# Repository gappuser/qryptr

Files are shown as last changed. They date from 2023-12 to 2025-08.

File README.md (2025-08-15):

# qryptr - airgapped ecc text messenger

Are you a smartphone user worried about [spyware](https://en.wikipedia.org/wiki/Spyware), [advanced actors](https://en.wikipedia.org/wiki/Advanced_persistent_threat), [backdoors](https://en.wikipedia.org/wiki/Backdoor_(computing)), [zero-days](https://en.wikipedia.org/wiki/Zero-day_vulnerability) or [side-channel attacks](https://en.wikipedia.org/wiki/Side-channel_attack)? These routinely bypass end-to-end encryption through keyloggers, screen capture and compromised keys. Smartphones are part of complex ecosystems with dozens of hardware and software components and remain vulnerable despite vendor and political efforts.

We introduce a simple, offline, airgapped device to counter such threats. 

Plain text messages are ECC encrypted and displayed as QR codes. These QR codes can be photographed and shared using your smartphone. This method offers additional endpoint security as plaintext and cryptographic keys are physically seperated from your smartphone.

This repository contains all hardware and software to create such a device, which allows text messages of up to 299 characters.

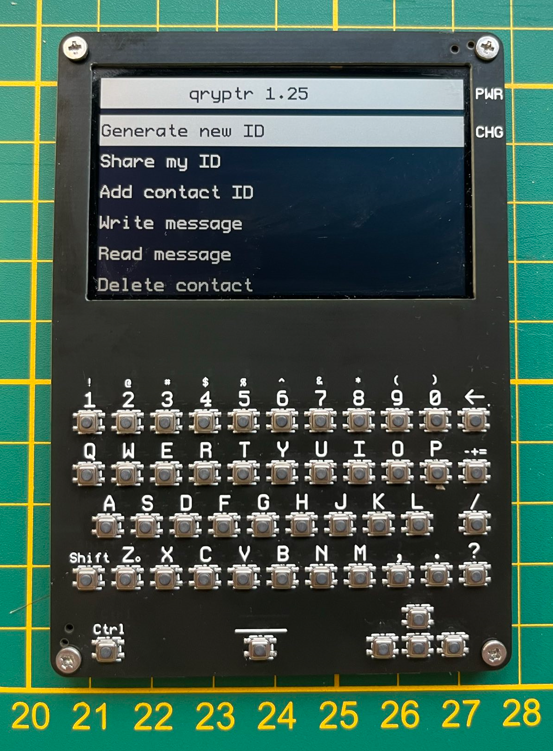
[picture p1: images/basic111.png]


# How it works
The device has cryptographic software, a keyboard, camera, screen and is based on the RP2040 microcontroller.

Each user has a device. Upon receiving it, the user can generate his/her ECC keypair. The user's ECC keypair uniquely identifies him/her, that is why it is referred to as the user ID.

The public key of the user ID can be displayed as a QR code. Another user can add that user ID scanning it. This is preferably done in-person, not remotely, to prevent man-in-the-middle attacks. 

After two users have added each others' ID's, they can write text messages which are ECC encrypted, base64 encoded and displayed as QR codes.

Using their smartphones, users can photograph/share these QR-codes with their preferred messaging app, such as Signal, Whatsapp, Telegram, Viber, or even email or print the QR codes.

The recipient can scan the QR code with his/her device, which will read, decode, decrypt and display the text message. The recommended read distance is 10 cm between smartphone screen and camera. The letter "Z" is marked on the frontpanel to help a user center the qr code in front of the camera.

### Share and add IDs

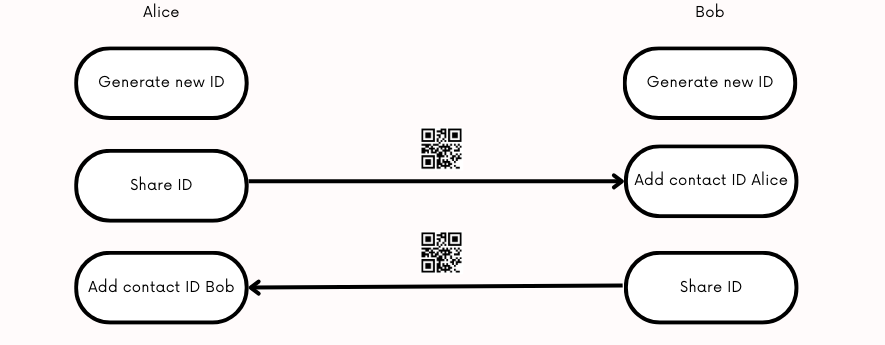
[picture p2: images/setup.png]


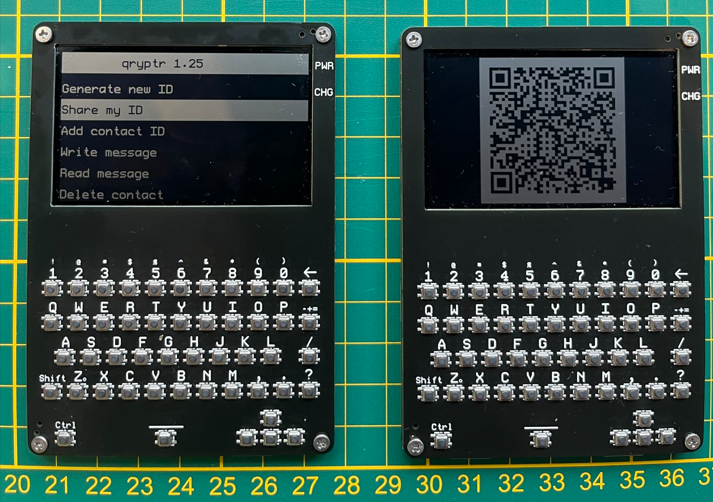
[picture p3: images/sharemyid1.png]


### Write and read messages

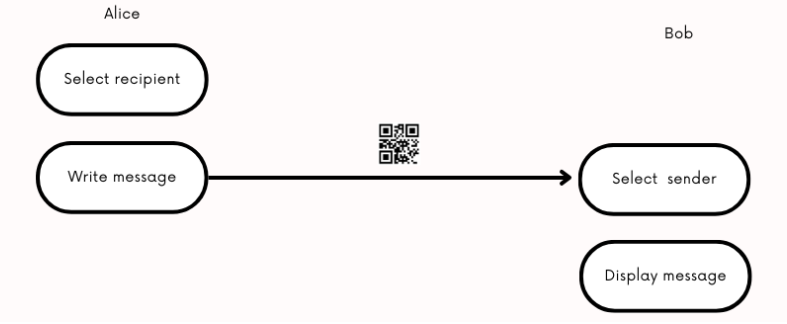
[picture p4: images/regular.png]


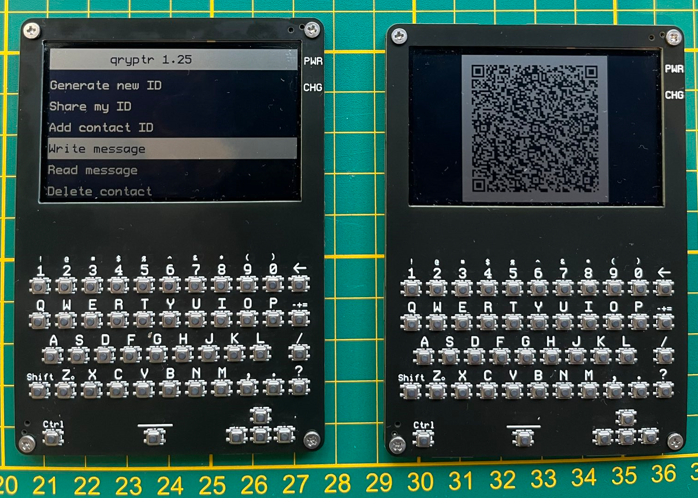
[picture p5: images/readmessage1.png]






# Use cases
-Sharing sensitive information between journalists, lawyers, political actors or civil servants.

-Sharing passwords between system administrators.

-Sharing passwords for crypto wallets.

-Sharing key material or passwords for HSM procedures.

-Thwart spyware or advanced threats.

# Implementation
## hardware
### Printed Circuit Boards (PCBs)
The device consists of 2 printed circuit boards (PCBs): a mainplate and frontplate with keys. We chose a microcontroller platform to minimize platform complexity and dependencies: the RP2040. Design files are available in the /hardware folder. With the Gerber, BOM and pick-and-place files, you can order directly from jlcpcb.com or other PCB manufacturers. 

Alternatively, you can view or clone these at the following urls to make adjustments.

https://oshwlab.com/thomas255/mainplate-public (click "clone")  

https://oshwlab.com/thomas255/frontplate-public (click "clone")

### Camera

QR codes are read using a hardware camera, the GM803, available on aliexpress. Get the GM803-S version with short focal range. This camera will read the QR code towards the serial interface of the RP2040.

### Display

We are using the Sharp LS027B7DH01 display, available on aliexpress. It is flat, requires few components, has a high resolution and low power requirements. Other u8g2 supported displays could be used as well with some adjustments.

### Other parts

Some parts needs to be ordered seperately from [lscs.com](https://www.lcsc.com/):

-LCSC#: C2911889 Clamshell 18P Bottom Contact Surface Mount FFC connector. We order this part seperately to solder it manually so that we can use one sided PCB assembly at JLCPCB to save costs. Alternatively, two sided assembly for the frontplate can be used at JLCPCB, in which case this part does not need to be ordered seperately.

-LCSC#: C2857713 18P Opposite Side 5cm P=0.5mm flat flexible cable to connect the frontplate (keyboard) with the mainplate

-LCSC#: C5151979 12P Opposite Side 5cm P=0.5mm flat flexible cable to connect the GM-803 camera to the mainplate

-M2 nuts and M2 bolts of 3mm length.

-A plastic spacer between the mainplate and frontplate, for mechanical stability and assembly, which can be 3d printed with the provided ./hardware/spacer.stl file.

-A 302040 lipo battery: https://www.aliexpress.com/item/33009055815.html

## software
We use the Arduino IDE.

Go to the board manager and install Arduino mbed OS RP2040 Boards (3.5.4). This should set target_platform=mbed_rp2040 in preferences.txt for the arduino IDE.

We use the Arduino mbed_rp2040 target platform, because we want to use the Sharp LS027B7DH01 display, and the earle philhower core does not allow changing the HW SPI pin assignment. We want to use different pins for driving the SPI display in the u8g2 display constructor, because the original pin assignment is very slow.

Using the library manager in the Arduino IDE, install the following libraries:

-QRCode by Richard Moore (https://github.com/ricmoo/qrcode/)

-U8G2 by Oliver Kraus (https://github.com/olikraus/u8g2)

-Crypto by Rhys Weatherley and Brandon Wiley (https://github.com/OperatorFoundation/Crypto)

To upload the software, connect with PC through USB, turn on device, upload ./software/qryptr.ino through the arduino IDE. If that does not work, there is a reset button. Turn off the device, hold the reset button, connect with PC, release the reset button. Then upload the arduino sketch through the arduino IDE.

Once uploaded, navigate the menu with the arrow buttons (left, right, up, down). There is no enter key. To select an option or continue, use the right arrow. You can always go back with left arrow or interrupt reading by pressing any key.

# Todos
## hardware
-Add resistor divider to measure the battery voltage

-Expose SWD pins on PCB to enable loading the software through SWD pins. This will allow us to disconnect the datalines from the USB port and prevent an attack vector.

-Improve keyboard

-Use rp2350 TRNG and possibly secure boot.

-RF and audio shielding to prevent side channel attacks.

-Use the HM01B0 camera instead.

## software
-Replace Arduino Crypto library with Monocypher (https://github.com/LoupVaillant/Monocypher). Monocypher is more widely used and more regularly updated.

-Create a software procedure to turn the camera on/off to save power.

-Implement soft poweroff after timeout.

-Implement symmetric encryption on the long-term private key of the user. This will require a password prompt for decrypting messages. Possibly use 2 passwords, a long one for starting up, and a shorter one for decrypting/encrypting.

-Enable multiple personal ID's (cryptographic keys)

-Add start and end tags for messages and keys, so that it is clear whether a valid messages/key was received. This will prevent bad reads from crashing the device as well.

-Use camera without character encoding (raw bytes).

-Write special characters (diacritics) with ctrl button.

-On screen arrows to make navigation more intuitive.

-Support reset-after-x-messages, to reset the device after decrypting or encrypting a certain amount of messages.

-Support multiple languages.

-Support deadman's switch, that is, reset the device upon startup if a wrong or particular password is used, or after a particular time period (though this is hard without a real time clock).

-Research backup-to-screen, that is, backup some contacts by displaying them on the screen and letting users decide how to back them up (writing them down or making a photo).

-Reshare keys to trusted contacts, possibly by signing them as well.

-Possible enable local, offline password manager.

# FAQ
## hardware
Q: Could we run the whole device on 3.3V? 

A: The Sharp LS027B7DH01 display requires 5V according to the specifications, although it seems to work on 3.3V as well. Possibly, the charge boost circuit could be left out if the display is used at 3.3V.

Q: Could we create a single PCB instead of a backplate and frontplate?

A: Yes, it could be done, although a singular PCB would need double-sided PCB assembly which is more expensive for small quantities @ JLCPCB. It likely would require a 4 layer PCB instead of 2 layer PCBs. Also, a seperate backplate would need to be introduced.

Q: How about using an epaper display instead of the Sharp display?

A: It has been considered, but the Sharp display has a higher refresh rate and is very flat and easy to integrate with just a couple of capacitors. The Sharp display is easy to use with the U8G2 library. There are other advantages to using epaper displays such as low glare which would make it easier to photograph the screen, so this could still be a good option.

## software
Q: How is encryption done?

A: Using the arduino Crypto library, with 32 byte ECC curve25519 keys, using ChaChaPoly cipher. Documented in the code, according to the procedure described here:

https://crypto.stackexchange.com/questions/101420/eccdh-direct-or-with-temporary-ecc-keypairs

# Assembly
Place the battery and solder the wires as shown below to the pads.

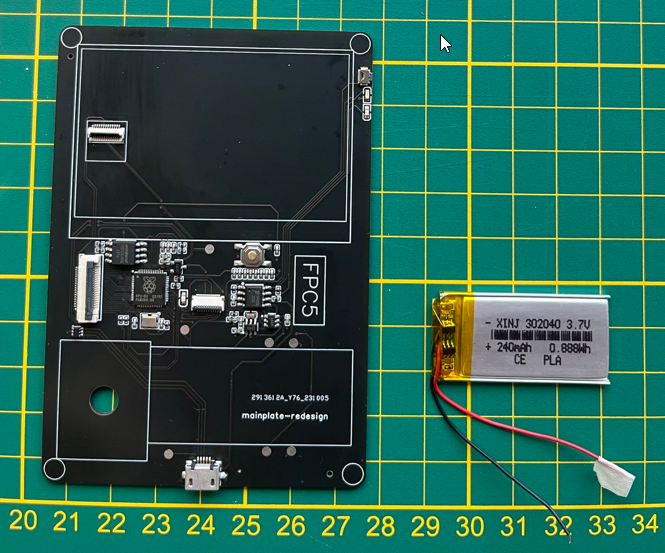
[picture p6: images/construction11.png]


Place the 3d printed spacer as shown below, insert the m2 nuts with some glue.

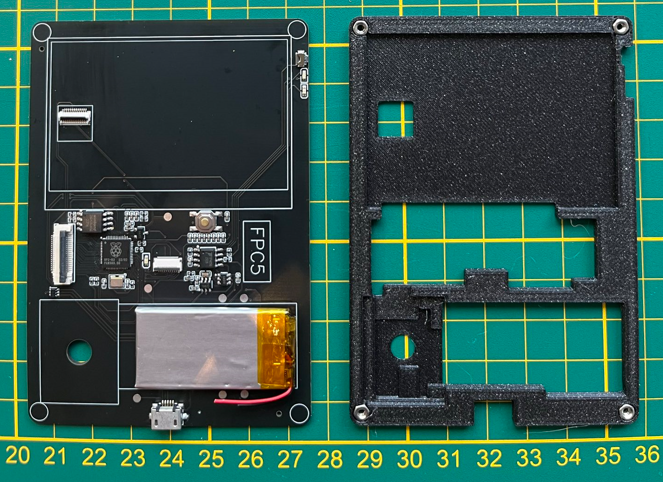
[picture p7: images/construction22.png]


Connect the 18 pin keyboard connector as shown below, place the GM-803 camera module and connect with the 12 pin ffc connector cable.

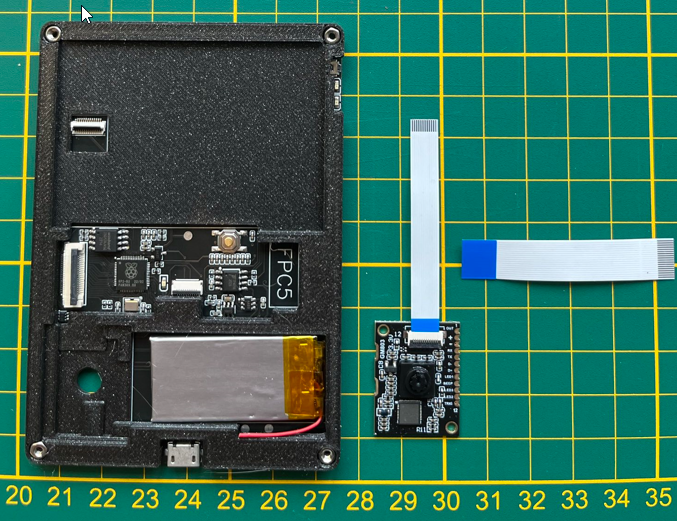
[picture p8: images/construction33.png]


Place the screen as shown below.

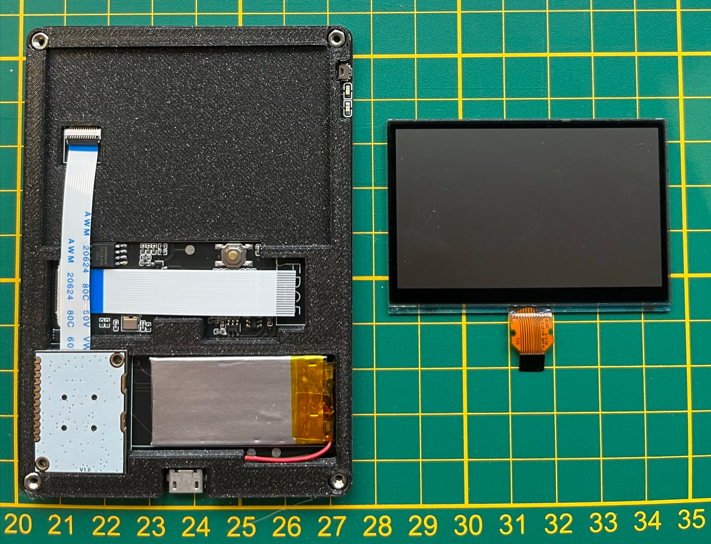
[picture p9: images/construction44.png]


Solder the frontplate 18 pin connector (or order an assembled frontplate from JLCPCB), and connect it. Soldering this 0.5mm pitch connector can be a bit tricky.

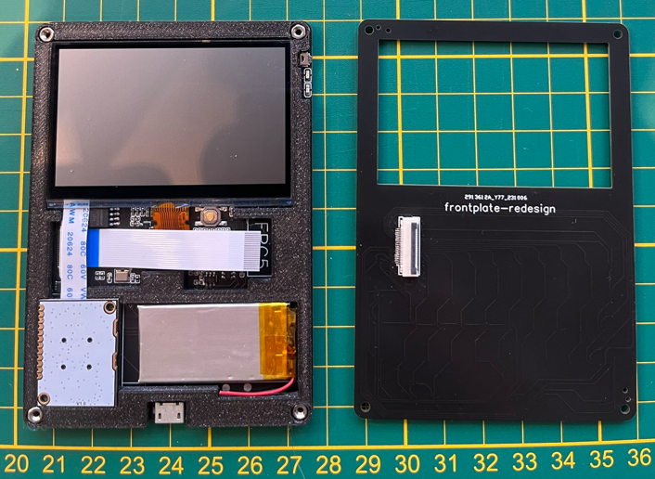
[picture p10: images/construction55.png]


Use the m2 3mm bolts to screw the frontplate down.

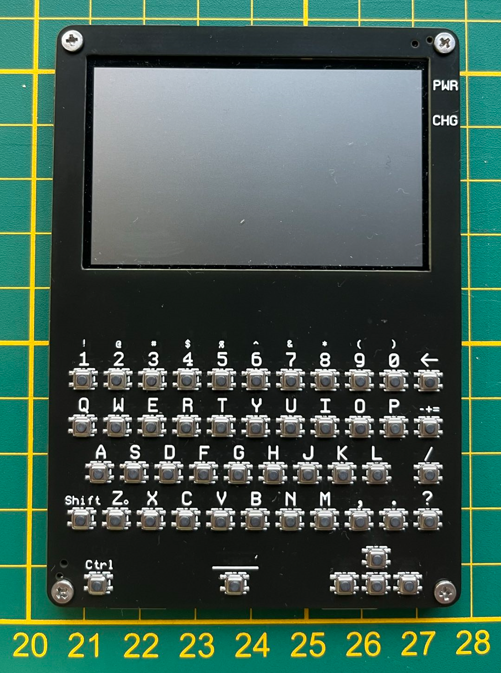
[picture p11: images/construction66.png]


## Setup GM803 camera

After charging, a green led will light up. Turn on the device (PWR top right push button). You have to enable serial output of the GM803 camera. To do so, scan the following QR codes.

### Reset (GM803 factory default)


### Enable serial output


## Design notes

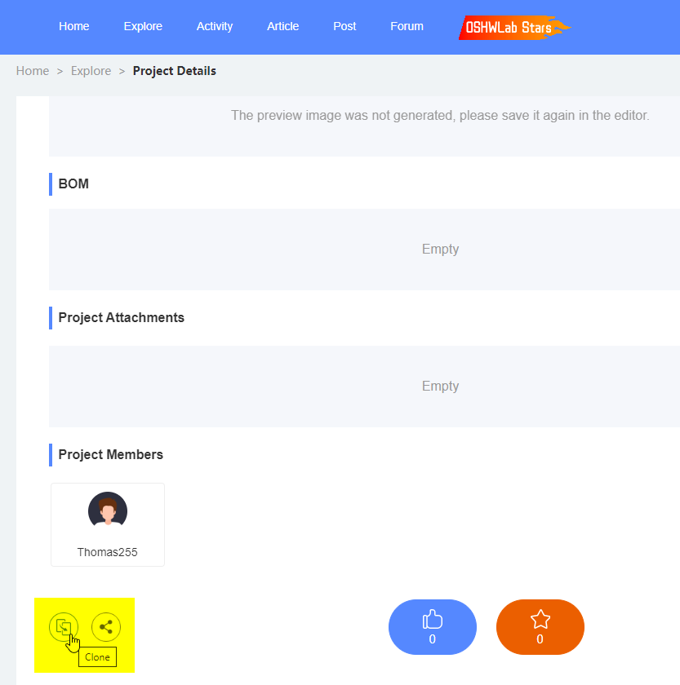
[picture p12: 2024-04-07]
images/clone.png

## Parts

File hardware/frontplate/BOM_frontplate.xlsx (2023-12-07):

No. | Quantity | Comment | Designator | Footprint | Value | Manufacturer Part | Manufacturer | Supplier Part | Supplier | Primary Category | Secondary Category
1 | 49 | TSA007B1518A | 0,1,2,3,4,5,6,7,8,9,+-1,//1,A1,B1,BACK1,C1,COMMA1,CTRL1,D1,DOT1,DOWN1,E1,F1,G1,H1,I1,J1,K1,L1,LEFT1,M1,N1,O1,P1,Q1,QM1,R1,RIGHT1,S1,SHIFT1,SPACE1,T1,U1,UP1,V1,W1,X1,Y1,Z1 | SW-SMD_4P-L3.4-W3.4-P2.00-LS4.0_YTSA007AXXXX |  | TSA007B1518A | BZCN(博众电气) | C2888918 | LCSC | Key/Switch | Tactile Switches
2 | 1 | 0.5K-DX-18PWBG | FPC2 | FPC-SMD_18P-P0.50_HDGC_0.5K-DX-18PWBG |  | 0.5K-DX-18PWBG | HDGC(华德共创) | C2911889 | LCSC | Connectors | FFC/FPC Connectors

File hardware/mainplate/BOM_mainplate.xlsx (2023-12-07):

No. | Quantity | Comment | Designator | Footprint | Value | Manufacturer Part | Manufacturer | Supplier Part | Supplier | Primary Category | Secondary Category
1 | 7 | 2MM ROUND PAD | 3VLDOOUT?,3.3VMINBAT1,3.3VMINBAT?,3.3VPLUSBAT1,3.3VPLUSBAT?,5VCHPOUT?,5VUSBOUT? | PAD 2MM*2MM
2 | 4 | 10kΩ | ADC_R1,MEMR1,TPR1,TPR2 | R0402 |  | 0402WGF1002TCE | UniOhm | C25744 | LCSC
3 | 11 | 100nF | CAMCAP1,CAPBANK1,CAPBANK2,CAPBANK3,CAPBANK4,CAPBANK5,CAPBANK6,CAPBANK7,CAPBANK8,CAPBANK9,MEMC1 | C0402_NEW |  | CL05B104KO5NNNC | SAMSUNG | C1525 | LCSC
4 | 5 | 10uF | CAMCAP2,CHPC1,CHPC2,TPC1,TPC2 | C0402 | 10uF | CL05A106MQ5NUNC | SAMSUNG(三星) | C15525 | LCSC | Capacitors | Multilayer Ceramic Capacitors MLCC - SMD/SMT
5 | 1 | 2.2uF | CHPC3 | C0603 |  | CL10A225KO8NNNC | SAMSUNG(三星) | C23630 | LCSC
6 | 1 | SD6210A-5V-CHARGEPUMP | CHPU1 | SOT-23-6_L2.9-W1.6-P0.95-LS2.8-BL |  | SD6210A | SHOUDING(首鼎半导体) | C250809 | LCSC
7 | 1 | THD0510-12CL-GF | FPC1 | FPC-SMD_12P-P0.50_THD0510-12CL-GF |  | THD0510-12CL-GF | THD(台华达) | C283122 | LCSC
8 | 1 | THD0509-10CL-GF | FPC2 | FPC-SMD_10P-P0.50_THD0509-10CL-GF |  | THD0509-10CL-GF | THD(台华达) | C283136 | LCSC | Connectors | FFC/FPC Connectors
9 | 1 | 0.5K-DX-18PWBG | FPC6 | FPC-SMD_18P-P0.50_HDGC_0.5K-DX-18PWBG |  | 0.5K-DX-18PWBG | HDGC(华德共创) | C2911889 | LCSC | Connectors | FFC/FPC Connectors
10 | 1 | XC6206P332MR | LDOU1 | SOT-23-3_L2.9-W1.6-P1.90-LS2.8-BR |  | XC6206P332MR | TOREX(特瑞仕) | C5446 | LCSC
11 | 1 | MAX16054AZT+T | MAX1 | TSOT-23-6_L2.9-W1.6-P0.95-LS2.8-TL |  | MAX16054AZT+T | MAXIM(美信) | C79401 | LCSC
12 | 2 | 1kΩ | MEMR2,XOSCR1 | R0402 |  | 0402WGF1001TCE | UniOhm | C11702 | LCSC
13 | 1 | TS-1187A-B-A-B | MEMSW1 | SW-SMD_4P-L5.1-W5.1-P3.70-LS6.5-TL-2 |  | TS-1187A-B-A-B | XKBConnectivity(中国星坤) | C318884 | LCSC
14 | 1 | W25Q128JVSIQTR | MEMU1 | SOIC-8_L5.3-W5.3-P1.27-LS8.0-BL |  | W25Q128JVSIQTR | WINBOND | C97521 | LCSC
15 | 1 | 19-217/BHC-ZL1M2RY/3T | PILED1 | LED0603-R-RD_BLUE |  | 19-217/BHC-ZL1M2RY/3T | EVERLIGHT | C72041 | LCSC
16 | 3 | 2kΩ | R3,TPRLED1,TPRLED2 | R0402 | 2kΩ | 0402WGF2001TCE | UNI-ROYAL(厚声) | C4109 | LCSC | Resistors | Chip Resistor - Surface Mount
17 | 2 | 10kΩ | R11,R12 | R0402 | 10kΩ | 0402WGF1002TCE | UNI-ROYAL(厚声) | C25744 | LCSC | Resistors | Chip Resistor - Surface Mount
18 | 3 | 1uF | SHARPC1,VREGC1,VREGC2 | C0402 |  | CL05A105KA5NQNC | SAMSUNG(三星) | C52923 | LCSC
19 | 1 | SMF05CT1G | STATIC1D? | SOT-363_L2.0-W1.3-P0.65-LS2.1-TL |  | SMF05CT1G | ON | C15879 | LCSC
20 | 1 | B3U-3000P | SW1 | KEY-SMD_B3U-3000P |  | B3U-3000P | OMRON(欧姆龙) | C963349 | LCSC | Key/Switch | Tactile Switches
21 | 1 | 19-217/GHC-YR1S2/3T | TPLEDG1 | LED-0603 |  | 19-217/GHC-YR1S2/3T | EVERLIGHT | C72043 | LCSC
22 | 1 | 19-213/Y2C-CQ2R2L/3T(CY) | TPLEDY1W? | LED0603-R-RD |  | 19-213/Y2C-CQ2R2L/3T(CY) | EVERLIGHT(亿光) | C72038 | LCSC
23 | 1 | TP4056 | TPU1 | SOP-8_EP_150MIL |  | TP4056 | TOPPOWER | C16581 | LCSC
24 | 1 | RP2040 | U1 | LQFN-56_L7.0-W7.0-P0.4-EP |  | RP2040 | RaspberryPi(树莓派) | C2040 | LCSC
25 | 1 | U-F-M5SS-W-1 | USB1 | MICRO-USB-SMD_U-F-M5SS-W-1 |  | U-F-M5SS-W-1 | 韩国韩荣 | C145783 | LCSC
26 | 2 | 22Ω | USBR1,USBR2 | R0402 |  | 0402WGF220JTCE | UniOhm | C25092 | LCSC
27 | 2 | 33pF | XOSCC1,XOSCC2 | C0402 |  | 0402CG330J500NT | FH | C1562 | LCSC
28 | 1 | 12MHz | XOSCX1 | OSC-SMD_4P-L3.2-W2.5-BL |  | X322512MSB4SI | YXC | C9002 | LCSC

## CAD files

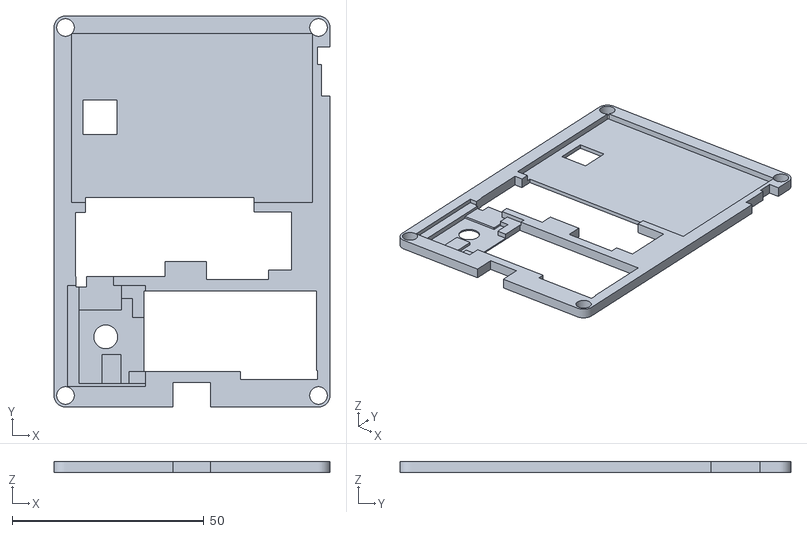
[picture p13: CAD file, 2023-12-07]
hardware/spacer.stl
72.0 x 102.0 x 3.00

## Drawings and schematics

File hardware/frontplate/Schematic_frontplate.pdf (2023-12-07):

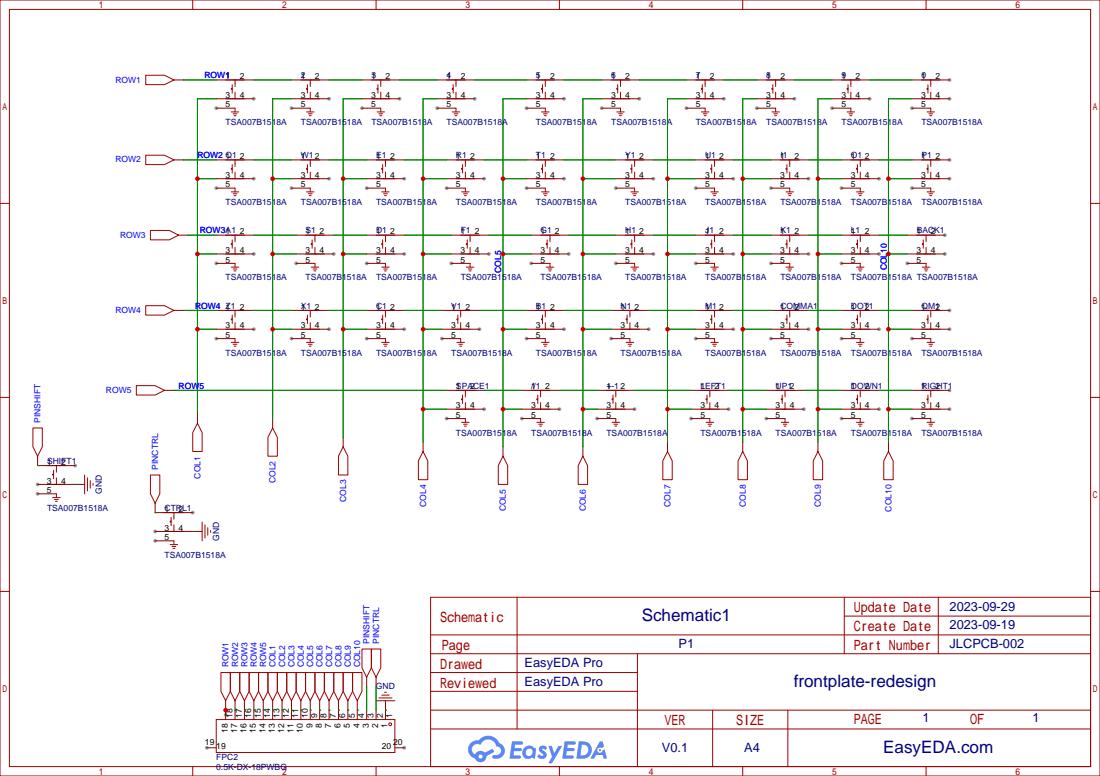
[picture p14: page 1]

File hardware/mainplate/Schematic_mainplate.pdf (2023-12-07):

# 0.5K-DX-18PWBG PICO_GP⁶_ROW⁵

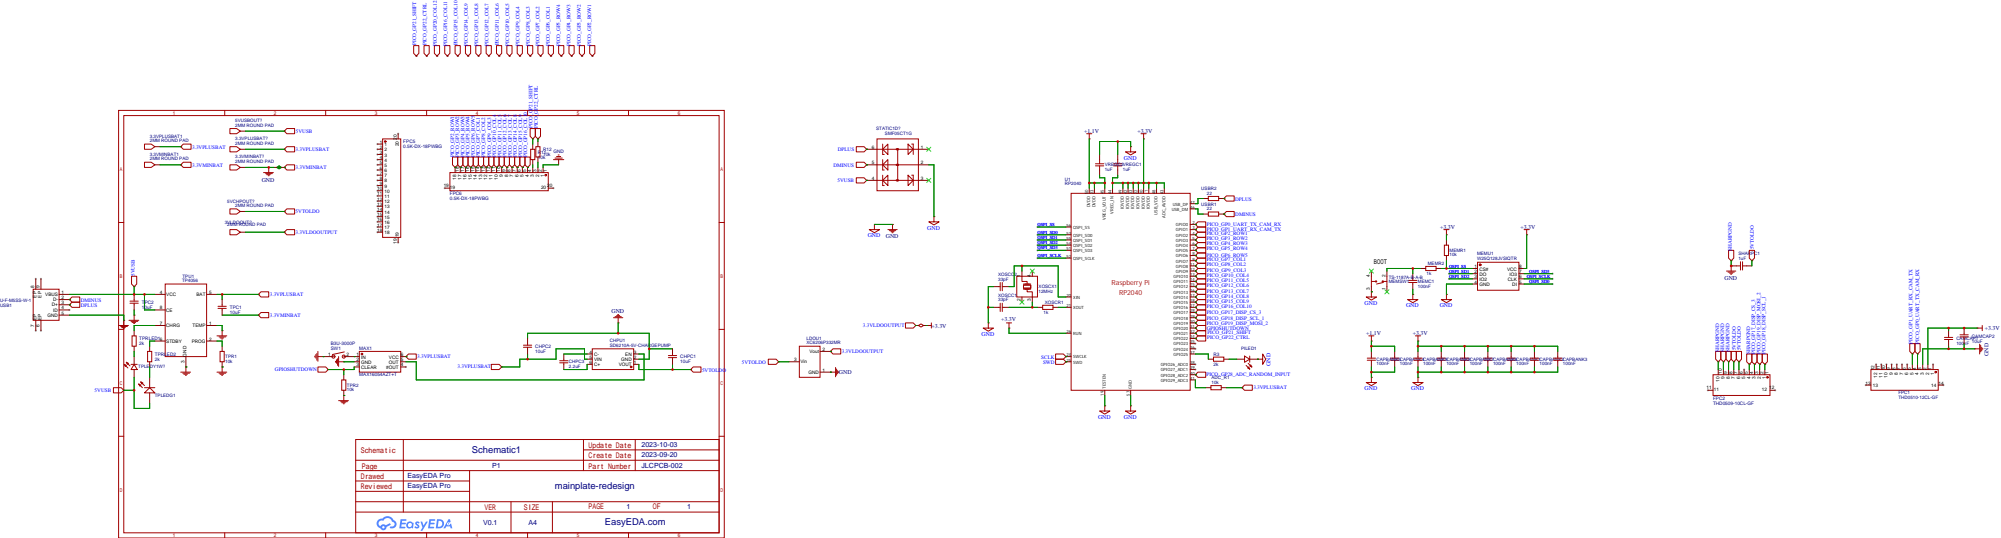
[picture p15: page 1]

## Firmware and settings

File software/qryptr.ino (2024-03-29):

//Copyright (C) 2024 Thomas Schellekens

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

//TODOS
//better prompts
//on screen arrows to indicate back/forth
//voltage readings of battery
//write special characters with control button
//multiple IDs
//use camera without character encoding. Currently, the GM-803 will always apply character encoding (UTF-8) to any byte. This means we need to apply base64 encoding before encoding into a QR code.
//Section 7.8 of the GM-803 manual seems to suggest there is a way to turn off character encoding, but this is not clear yet. We'd prefer to send raw bytes instead of base64-encoded raw bytes because it would allow for longer messages
//add option for symmetric encryption of private key (password prompt to make sure the private key is not kept in plain form on the memory chip)
//add <start> and <end> tags for messages and keys, so that upon decryption, it is clear whether a valid message was received or whether a error should be displayed


//Pin assignment
//Keyboard
//PICO_GP2_ROW1                                   
//PICO_GP3_ROW2  
//PICO_GP4_ROW3  
//PICO_GP5_ROW4  
//PICO_GP6_ROW5
//PICO_GP7_COL1
//PICO_GP8_COL2
//PICO_GP9_COL3
//PICO_GP10_COL4
//PICO_GP11_COL5
//PICO_GP12_COL6
//PICO_GP13_COL7
//PICO_GP14_COL8
//PICO_GP15_COL9
//PICO_GP16_COL10
//Display
//PICO_GP17_DISP_CS_3 
//PICO_GP18_DISP_SCL_1 
//PICO_GP19_DISP_MOSI_2 
//GP_20 GPIOSHUTDOWN        (todo for soft shutdown/timeout shutdown)
//PICO_GP21_SHIFT
//PICO_GP22_CTRL
//GP_23 unused
//GP_24 unused
//GP25 PI_LED for testing purposes
//GP28 ADC2 random input for ring oscillator (rosc)
//GP29 ADC3 10kOhm to battery for voltage indicator. Needs a resistor voltage divider still.


//CHARACTER ENCODING
//GM803 will always apply a character encoding, will not send pure bytes from QR code. So ecc keys need to be encoded with base64 (33% overhead).
//the terminal character is not an alphanumeric character. which causes ricmoo/qrcode to encode as BYTES, with all limitations that come along with that..
//strlen(), which is used by ricmoo/qrcode, only works if a null terminator is present.
//but that null terminator will be interpreted as a byte, which causes ricmoo/qrcode to never switch to alphanumeric mode..
//so, you have to use base64 encoding.


//FLASH WRITE STUFF
//always need to erase first.
//erase minimum is 4096 bytes
//write is 256 bytes minium. But can you only program bytes from a certain sector that was erased.
//have one fixed location for pub and private key (sector -2 and -3 before sector -200)
//https://www.makermatrix.com/blog/read-and-write-data-with-the-pi-pico-onboard-flash/
//we save contacts on individual sectors, 200 sectors from the end of the available memory. So we can have 200 contacts.

//Cryptographic procedures follow this structure:
//https://crypto.stackexchange.com/questions/101420/eccdh-direct-or-with-temporary-ecc-keypairs

extern "C" {
  #include <hardware/sync.h>
  #include <hardware/flash.h>
};

#include <Arduino.h>
#include <U8g2lib.h>
#include <qrcode.h>
#include <SPI.h>
#include <types.h>
#include <stdio.h>
#include <stdlib.h>
#include <gpio.h>
#include <uart.h>
#include <string.h>


//Cryptography libraries from Rhys Weatherly and Brandon Wiley
//https://www.arduino.cc/reference/en/libraries/crypto/
#include <Crypto.h>
#include <Curve25519.h>
#include <RNG.h>
#include <SHA256.h>
#include <HKDF.h>
#include <hardware/structs/rosc.h>
#include <ChaChaPoly.h>
#include <Base64.h>


#define MAX_PLAINTEXT_LEN 332
#define FLASH_TARGET_OFFSET (PICO_FLASH_SIZE_BYTES - FLASH_SECTOR_SIZE)

//old 128x64 st7920 lcd, someone may still want to try this as an alternative display
//U8G2_ST7920_128X64_F_SW_SPI u8g2(U8G2_R0, /* clock=*/ 13, /* data=*/ 11, /* CS=*/ 10, /* reset=*/ 8);

//Works only with the official rp2040 mbed arduino core, not with the earle philhower core, because you cannot change the HW SPI pin assignment. And the original pin assignment is very slow.
//u8g2 sendBuffer takes about 196ms, found no room for improvement.
U8G2_LS027B7DH01_400X240_F_4W_HW_SPI u8g2(U8G2_R0, 17, U8X8_PIN_NONE);


//UART variables, for use with the GM-803 camera
#define UART0_ID        uart0
#define UART0_BAUD_RATE 9600
#define DATA_BITS 8
#define STOP_BITS 1
#define PARITY    UART_PARITY_NONE

//GPIO pins 12, 14, 15 are hardware SPI pins based on mbed2040 library (other rp2040 arduino implementation could only use software SPI pins for display initialization)
int pinrow1 = 2;
int pinrow2 = 3;
int pinrow3 = 4;
int pinrow4 = 5;
int pinrow5 = 6;
int pincolumn1 = 7;
int pincolumn2 = 8;
int pincolumn3 = 9;
int pincolumn4 = 10;
int pincolumn5 = 11;
int pincolumn6 = 12;
int pincolumn7 = 13;
int pincolumn8 = 14;
int pincolumn9 = 15;
int pincolumn10 = 16;
int pinshift = 21;
int pincontrol= 22; 

int rowPins[5] = {pinrow1, pinrow2, pinrow3, pinrow4, pinrow5};  
int columnPins[10] = {pincolumn1, pincolumn2, pincolumn3, pincolumn4, pincolumn5, pincolumn6, pincolumn7, pincolumn8, pincolumn9, pincolumn10};  
int debouncetime = 40;    //40ms    //useless since rendering screen takes 150ms.


//buffer required by main loop, needs to be global
//char mainloopbuf[10];   this is too little. it crashes.
char mainloopbuf[100];  
int mainloopbufpos = 0;
int prevmainloopbufpos = 0;
int * mainloopbufpospointer = &mainloopbufpos;
int * prevmainloopbufpospointer = &prevmainloopbufpos;

long lastdebouncetime[5][22] = {0};
int lastinputstate[5][22] = {1};

bool rendermainagain = true;

//these are global for now and used by prompt, selectContact, (main) loop. Not pretty but practical for now. 
int menustate = 0;
int prevmenustate = 0;   
int menuhighlight = 0;    
int state = 0; 

//for enabling scrolling
int startpositionarrowed = 0;   //for scrolling through the page of writing a message. the starting line, taking into account up and down arrows.
int uparrows = 0;               //keep track of number of up arrows pressed
int downarrows = 0;             //keep track of number of down arrows pressed

//ORIGINAL SETUP 19 height
//u8g2.setFont(u8g2_font_profont29_mf);
//int menurowcount = 5;   
//int screenwidth = 400;
//int screenheight = 240;
//int menuitemboxy = 40;
//int menuitemboxytextoffset = 30;
//int headermargin = 8;
//int menuitemboxxtextoffset = 2;

//SMALLER SETUP 14 pixel height
//u8g2.setFont(u8g2_font_profont22_mf);
int menurowcount = 6;   
int screenwidth = 400;
int screenheight = 240;
int menuitemboxy = 34;
int menuitemboxytextoffset = 24;
int headermargin = 8;
int menuitemboxxtextoffset = 2;
int maxcharacters = 32;           //maximum characters on single line given this font size.


//u8g2.setFont(u8g2_font_profont17_mf);    //11 pixel height
//u8g2.setFont(u8g2_font_profont15_mf);    //9 pixel height

int mainmenuitemstotal = 7;   //including 0, total number of items in mainmenustrings
char * mainmenustrings[] = {"Generate new ID", "Share my ID", "Add contact ID", "Write message", "Read message", "Delete contact", "Replace contact", "Reset"};

bool displaydecryptmessage = false;
bool globalbackspace = false;
bool firstrender = true;

//We will use int char values 17, 18, 19, 20 for up, right, down, left
//B is backspace
char keyboardlowercase[5][10] = { { '1', '2', '3', '4', '5', '6', '7', '8', '9', '0' },
                                  { 'q', 'w', 'e', 'r', 't', 'y', 'u', 'i', 'o', 'p' },
                                  { 'a', 's', 'd', 'f', 'g', 'h', 'j', 'k', 'l', 'B' },
                                  { 'z', 'x', 'c', 'v', 'b', 'n', 'm', ',', '.', '?'},
                                  { '0', '0', '0', ' ', '/', '_', 20, 17, 19, 18}};
                                  
char keyboarduppercase[5][10] = { { '!', '@', '#', '$', '%', '^', '&', '*', '(', ')' },
                                  { 'Q', 'W', 'E', 'R', 'T', 'Y', 'U', 'I', 'O', 'P' },
                                  { 'A', 'S', 'D', 'F', 'G', 'H', 'J', 'K', 'L', 'B' },
                                  { 'Z', 'X', 'C', 'V', 'B', 'N', 'M', '<', '>', '/'},
                                  { '0', '0', '0', ' ', '|', '_', 20, 17, 19, 18}};
                                  
struct TestVector
{
    const char *name;
    uint8_t key[32];
    uint8_t plaintext[MAX_PLAINTEXT_LEN];
    uint8_t ciphertext[MAX_PLAINTEXT_LEN];
    uint8_t authdata[16];
    uint8_t iv[16];
    uint8_t tag[16];
    size_t authsize;
    size_t datasize;
    size_t tagsize;
    size_t ivsize;
};                                 
                                  


void setup_uart(){
  uart_init(UART0_ID, UART0_BAUD_RATE);
  gpio_set_function(0, GPIO_FUNC_UART);
  gpio_set_function(1, GPIO_FUNC_UART);
  
  // Set UART flow control CTS/RTS, we don't want these, so turn them off (for GM-803)
  uart_set_hw_flow(UART0_ID, false, false);
  
  // Set our data format, as required by GM-803 camera
  uart_set_format(UART0_ID, DATA_BITS, STOP_BITS, PARITY);  
}

void setupInput(){

  pinMode(2, OUTPUT);
  pinMode(3, OUTPUT);  // Set the button as an input
  pinMode(4, OUTPUT);  // Set the button as an input
  pinMode(5, OUTPUT);  // Set the button as an input
  pinMode(6, OUTPUT);  // Set the button as an input
  
  pinMode(7, INPUT_PULLUP);  // Set the button as an input
  pinMode(8, INPUT_PULLUP);  // Set the button as an input
  pinMode(9, INPUT_PULLUP);  // Set the button as an input
  pinMode(10, INPUT_PULLUP);  // Set the button as an input
  pinMode(11, INPUT_PULLUP);  // Set the button as an input
  pinMode(12, INPUT_PULLUP);  // Set the button as an input
  pinMode(13, INPUT_PULLUP);  // Set the button as an input
  pinMode(14, INPUT_PULLUP);  // Set the button as an input
  pinMode(15, INPUT_PULLUP);  // Set the button as an input
  pinMode(16, INPUT_PULLUP);  // Set the button as an input
  pinMode(21, INPUT_PULLUP);  // Set the button as an input
  pinMode(22, INPUT_PULLUP);  // Set the button as an input

  digitalWrite(2, HIGH);  // Pull the button high
  digitalWrite(3, HIGH);  // Pull the button high
  digitalWrite(4, HIGH);  // Pull the button high
  digitalWrite(5, HIGH);  // Pull the button high
  digitalWrite(6, HIGH);  // Pull the button high

}

void setDriveStrenthLow(){
   gpio_set_drive_strength (2, GPIO_DRIVE_STRENGTH_2MA);
   gpio_set_drive_strength (3, GPIO_DRIVE_STRENGTH_2MA);
   gpio_set_drive_strength (4, GPIO_DRIVE_STRENGTH_2MA);
   gpio_set_drive_strength (5, GPIO_DRIVE_STRENGTH_2MA);
   gpio_set_drive_strength (6, GPIO_DRIVE_STRENGTH_2MA);
   gpio_set_drive_strength (7, GPIO_DRIVE_STRENGTH_2MA);
   gpio_set_drive_strength (8, GPIO_DRIVE_STRENGTH_2MA);
   gpio_set_drive_strength (9, GPIO_DRIVE_STRENGTH_2MA);
   gpio_set_drive_strength (10, GPIO_DRIVE_STRENGTH_2MA);
   gpio_set_drive_strength (11, GPIO_DRIVE_STRENGTH_2MA);
   gpio_set_drive_strength (12, GPIO_DRIVE_STRENGTH_2MA);
   gpio_set_drive_strength (13, GPIO_DRIVE_STRENGTH_2MA);
   gpio_set_drive_strength (14, GPIO_DRIVE_STRENGTH_2MA);
   gpio_set_drive_strength (15, GPIO_DRIVE_STRENGTH_2MA);
   gpio_set_drive_strength (16, GPIO_DRIVE_STRENGTH_2MA);
   gpio_set_drive_strength (21, GPIO_DRIVE_STRENGTH_2MA);
   gpio_set_drive_strength (22, GPIO_DRIVE_STRENGTH_2MA);   
}
void setup()
{
  setup_uart();

  for(int i = 0;i<5;i++){
    for(int j = 0; j<22;j++){
      lastdebouncetime[i][j] = 0;
      lastinputstate[i][j] = 1;
    }
  }
  
  u8g2.begin();
  u8g2.setDisplayRotation(U8G2_R0);
  u8g2.clearBuffer();  
  //this is the original for menurowcount5
  //u8g2.setFont(u8g2_font_profont29_mf);   //19 pixel height, no overlap, mono, full
  u8g2.setFont(u8g2_font_profont22_mf);                //14 pixel height, no overlap, mono, full
  pinMode(20, OUTPUT);    //GPIO shutdown for software-controlled shutdown after timeout
  digitalWrite(20, LOW);  //Pull shutdown low.
  //builtin led
  pinMode(25, OUTPUT);
  
  //adc's for sampling battery voltage. Needs a voltage divider on pcb still.
  //adc_init();
  //adc_gpio_init(29);
  //adc_select_input(3);
 
  setupInput();
  
  //set all keyboard pins to 2mA..
  setDriveStrenthLow();
}

//These camera control functions are not working yet. The hex strings come from the GM-803 camera module manual
void cameraReset(){
  setup_uart();
  const char camreset[] = "\x7E\x00\x08\x01\x00\xD9\x50\xAB\xCD";
  uart_puts(UART0_ID, camreset);
  delay(50);
  uart_deinit(UART0_ID);
}
void cameraSleep(){
    setup_uart();
    const char camsleep[] = "\x7E\x00\x08\x01\x00\xD9\xA5\xAB\xCD";
    uart_puts(UART0_ID, camsleep);
    delay(50);
    uart_deinit(UART0_ID);
}
void cameraWake(){
    setup_uart();
    const char camwake[] = "\x7E\x00\x08\x01\x00\xD9\x00\xAB\xCD";
    uart_puts(UART0_ID, camwake);
    delay(50);
    uart_deinit(UART0_ID);
}
//turning off UTF-8 encoding, and sending pure data (pure bytes) could potentially allow us to not use base64 encoding, saving 33% space in our QR codes.
void cameraPureData(){
    const unsigned char camsleep[] = {0x7E, 0x00, 0x08, 0x01, 0x00, 0x60, 0x00, 0xAB, 0xCD };
}
void cameraWithProtocol(){
    const unsigned char camwake[] = {0x7E, 0x00, 0x08, 0x01, 0x00, 0x60, 0x01, 0xAB, 0xCD };
}

//helper functions to print keys to serial output when writing/debugging.
void printuCharAsHex(unsigned char c) {
  char hexCar[2];
  sprintf(hexCar, "%02X", c);
  Serial.print(hexCar);
}
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
void loop(){
  //collectinput for the main menu (mainloopbuf)
  collectInput(mainloopbuf, mainloopbufpospointer, prevmainloopbufpospointer);
  //check last character main menu buffer (stfbuf), set state accordingly
  evaluateBuffers(mainloopbuf, *mainloopbufpospointer, *prevmainloopbufpospointer, mainmenuitemstotal);      
  //act upon the state 
  executeMenuAction(state);
}

void executeMenuAction(int passedMenuState){
  switch (passedMenuState){
  case 0:{  //no action, just render the menu
    renderMenu(mainmenustrings, "        qryptr 1.25", mainmenuitemstotal);
    break;
  }
  case 1:{  //generate new keypair for user. this represent the cryptographic identity of the user.
    bool idexists = true;
    idexists = !isSectorEmpty(-2) && !isSectorEmpty(-3);    //pub and priv keys reside at sector -2 and -3 conventionally
    if(!idexists){
      generateKeypair();                              
      displayMessage("New ID generated",16,32);
      awaitAnyButton();
    }
    else{
      int generatecontinue = 0;
      char* options[] = {"No", "Yes"};
      char* str = "Found existing key. Overwrite?";
      generatecontinue = prompt(str, options, 2);
      if(generatecontinue == 1){
        generateKeypair();                              
        displayMessage("New ID generated",16,32);
        awaitAnyButton();
      }
    }
    returnToMain();
    break;  
  }
  case 2: {//share my public key as QR code on display
    bool idexists = true;
    idexists = !isSectorEmpty(-2) && !isSectorEmpty(-3);    //pub and priv keys reside at sector -2 and -3 conventionally

    if(idexists){

      //this could be done more elegantly, instead of having 2 arrays.
      uint8_t targetarray[32] = {0};
      readKey(targetarray, 32, -2, 0);                           
      char targetarray2[32] = {0};
      for(int i = 0;i<32;i++){
        targetarray2[i] = targetarray[i];
      }
      
      //We encode bytes of the public key as base64 characters before encoding it as a QR code.
      int inputStringLength = sizeof(targetarray2);
      int encodedLength1 = Base64.encodedLength(inputStringLength);
      Serial.println("encodedLength1 is "+String(encodedLength1));
      char encodedString[encodedLength1];
      Base64.encode(encodedString, targetarray2, inputStringLength);      
      remove_char(encodedString, '=');
      int noPadLength = sizeof(encodedString);

      int newLength = sizeof(encodedString);
      displayBufferAsQR(encodedString, newLength, 6, 0, 5, 16, 84, 0);    
      awaitAnyButton();
    }
    else{
        displayMessage("No ID found",16,32);
        awaitAnyButton();
    }
    returnToMain();
    break;
  }
  case 3:{      //add contact id
    char nameinputbuf[100]; 
    int nameinputbufpos = 0;
    int prevnameinputbufpos = 0;
    int * nameinputpospointer = &nameinputbufpos;
    int * prevnameinputpospointer = &prevnameinputbufpos;

    bool breakreturn = nameInputLoop(nameinputbuf, nameinputpospointer, prevnameinputpospointer);
    
    if(breakreturn){
      returnToMain();
      break;
    }
    else {                                               //succesfully put name in nameinputbuf (max 32). So read the QR code, and put the name plus key into the first empty sector.
      int targetsector = firstEmptySector();
      readContactIntoSector(targetsector, nameinputbuf, nameinputbufpos);
      break;
    }
    }
    case 4: {       //write message
      int amountOfContacts = firstEmptySector();
      if(amountOfContacts == 0){
        displayMessage("No contacts",2,32);
        awaitAnyButton();
        returnToMain();
        break;
      } 
      //in this case, we don't know how many contacts we have. so how do we allocate enough memory?
      //https://stackoverflow.com/questions/7652293/how-do-i-dynamically-allocate-an-array-of-strings-in-c
      char** strings = (char**)malloc(amountOfContacts * sizeof(char*));    
      for (int i = 0; i < amountOfContacts; i++){
        strings[i] = (char*)malloc((32+1) * sizeof(char));    //for now, every contact string can be of size 32, including null terminator.
      }
      //will put all the names in strings
      collectNames(amountOfContacts, strings);  
      int targetcontact = selectContact(strings, amountOfContacts, "select recipient");
      if(targetcontact!=-1){
          delay(500);
          writeMessageLoop(targetcontact);    
      }
      returnToMain();
      for (int i = 0; i < amountOfContacts; i++){
        free(strings[i]);
      }
      free(strings);
      break;
    }
    case 5: {       //read message
      int amountOfContacts = firstEmptySector();
      if(amountOfContacts == 0){
        displayMessage("No contacts",2,32);
        awaitAnyButton();
        returnToMain();
        break;
      } 
      char** strings = (char**)malloc(amountOfContacts * sizeof(char*));    
      for (int i = 0; i < amountOfContacts; i++){
        strings[i] = (char*)malloc((32+1) * sizeof(char));
      }
      collectNames(amountOfContacts, strings);  
      int targetcontact = selectContact(strings, amountOfContacts, "select sender");
      if(targetcontact!=-1){
          readmessage(targetcontact);    
      }
      returnToMain();
      for (int i = 0; i < amountOfContacts; i++){
        free(strings[i]);
      }
      free(strings);
      break;
    }
    case 6: {     //delete contact
      int amountOfContacts = firstEmptySector();
      if(amountOfContacts == 0){
        displayMessage("No contacts",2,32);
        awaitAnyButton();
        returnToMain();
        break;
      } 
      char** strings = (char**)malloc(amountOfContacts * sizeof(char*));    
      for (int i = 0; i < amountOfContacts; i++){
        strings[i] = (char*)malloc((32+1) * sizeof(char));    //for now, every string can be of size 32.
      }
      collectNames(amountOfContacts, strings);  
      int targetcontact = selectContact(strings, amountOfContacts, "delete contact");
      if(targetcontact!=-1){
          deleteContact(targetcontact, amountOfContacts);    
      }
      returnToMain();
      for (int i = 0; i < amountOfContacts; i++){
        free(strings[i]);
      }
      free(strings);
      break;
    }
    case 7: {     //replace contact 
      int amountOfContacts = firstEmptySector();
      if(amountOfContacts == 0){
        displayMessage("No contacts",2,32);
        awaitAnyButton();
        returnToMain();
        break;
      } 
      char** strings = (char**)malloc(amountOfContacts * sizeof(char*));    
      for (int i = 0; i < amountOfContacts; i++){
        strings[i] = (char*)malloc((32+1) * sizeof(char));    //for now, every string can be of size 32.
      }
      collectNames(amountOfContacts, strings);  
      int targetcontact = selectContact(strings, amountOfContacts, "replace contact");
      if(targetcontact!=-1){
          char targetRecipient[33];
          int targetRecipientLength = 0;
          int * targetRecipientLengthPointer = &targetRecipientLength;
          readRecipientNameAndLength(targetcontact,targetRecipient,targetRecipientLengthPointer);
          readContactIntoSector(targetcontact, targetRecipient, *targetRecipientLengthPointer);
      }
      returnToMain();
      for (int i = 0; i < amountOfContacts; i++){
        free(strings[i]);
      }
      free(strings);
      break;
    }
    case 8: {       //reset all, useful for resetting the entire memory
      char * options[] = {"No", "Yes"};
      char* str = "Reset everything? ";
      int confirm = 0;
      char* str2 = "Your contacts and keys will be lost ";
      int confirm2 = 0;
      confirm = prompt(str, options, 2);
      if(confirm == 1){
        confirm2 = prompt(str2, options, 2);
        if(confirm2 == 1){
          displayMessage("This may take a while",2,32);
          resetMemory();
          displayMessage("Everything reset",2,32);
          awaitAnyButton();
        }
      }
      returnToMain();
      break;
    }
    case 9: {
      //refer here for the ascii codes
      //https://github.com/olikraus/u8g2/wiki/fntgrpprofont
      char a1 = 224;
      char a2 = 225;
      char a3 = 226;
      char a4 = 227;
      char chararray1[4] = {a1, a2, a3, a4};
      displayMessage(chararray1, 10, 40);
      awaitAnyButton(); 
      returnToMain();
      break;
    }  
  }
}

//We still use several global variables. Reset them when returning from executeMenuAction.
void returnToMain(){
      startpositionarrowed = 0;
      uparrows = 0;
      downarrows = 0;
      menustate = 0;
      prevmenustate = 0;
      menuhighlight = 0;
      state = 0;
      rendermainagain = true;
      resetCharBuffer(mainloopbuf,mainloopbufpospointer, prevmainloopbufpospointer);
      delay(250);
}
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

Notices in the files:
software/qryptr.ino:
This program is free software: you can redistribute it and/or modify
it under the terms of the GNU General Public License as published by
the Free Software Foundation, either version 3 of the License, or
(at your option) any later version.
